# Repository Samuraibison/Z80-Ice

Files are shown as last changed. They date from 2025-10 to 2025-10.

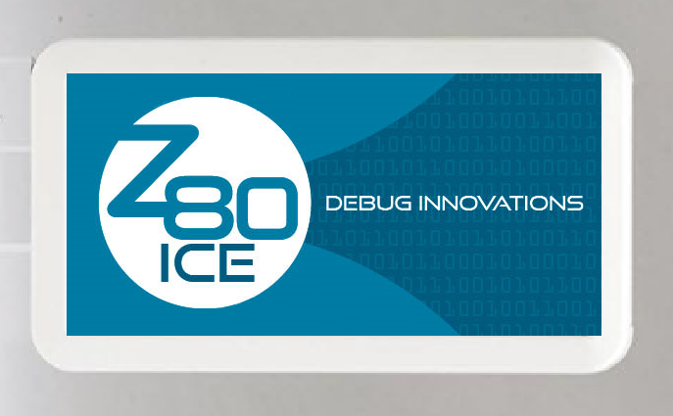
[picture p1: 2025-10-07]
Hardware/Box/Box_Label.png

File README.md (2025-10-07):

# Z80-Ice

**Work in Progress:** This project is still under development, and not all files are currently available.

## Foreword

All the source for this project was originally developed by **Dave Adshead**, under his company **Debug Innovations**. Unfortunately, Dave passed away in May 2025, so the resources here have been released for anybody interested in using it.

## About

The Z80 ICE is a project for a Z80 in-circuit emulator (ICE). The project aims to provide tools for debugging and developing Z80-based systems.

This repository contains:
- Firmware source code for the emulator.
- Hardware designs for the ICE.
- A basic desktop application for debugging.

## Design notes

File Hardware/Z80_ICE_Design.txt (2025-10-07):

ICE Options
===========

1. Design a Z80 in an FPGA
   Expensive, difficult to get right

2. Emulate a Z80 with a fast MCU
   May not be able to use the system clock
   Slow if all the pin timing is emulated

3. Control the clocks to the Z80
   No obvious way to set breakpoints
   No refresh when stopped
   Problems with interrupts, step over etc.
   Need target RAM to read/write registers etc.
   Need to mux the address bus between Z80 and PIC

4. Entirely soft solution using HALT for breakpoints
   User code can't use HALT
   Can't step through ROM code
   Need target RAM to read/write registers etc.
   Need to mux the address bus between Z80 and PIC

5. Our solution below...

See also http://www.primrosebank.net/computers/z80/z80_special_reset.htm
for short reset designed to be used with an ICE

Z80 ICE
=======

Z80 CPU (20MHz)
CPLD
64K x 8-bit breakpoint RAM
Control CPU (PIC) & debug interface

Debugger needs to be able to...

1. Reset CPU
2. Read/write system memory
3. Set/clear breakpoints
4. Set breakpoints
5. Read/write Z80 registers
6. Stop the CPU and read the PC

Breakpoint RAM bits
-------------------

0 : Code (execution) breakpoint
1 : Data read breakpoint
2 : Data write breakpoint
3 : Address is ROM / write protected (not implemented)

I/O read/write breakpoint??
Tracepoints?
Full trace?

The Z80 address bus is connected to the system and the
breakpoint RAM.  Z80 memory requests always read the
breakpoint RAM but the control lines nRD nWR etc. are gated
before they go to the system so that the requests can be
prevented from accessing system memory.  When running user
user code, all the control lines are active to the system.

The system provides the clock so it can't be stopped.

To stop the CPU, we could...

1. Stop the clock - that would stop refreshing DRAM or
2. Insert infinite wait states (addr wouldn't change).
   Would also stop DRAM refresh or
3. Execute NOPs (addr would go round 0-64K).  I suspect it
   would accept an interrupt, change addr, then continue
   executing NOPs and stay in interrupt state.
4. Execute a HALT - this would also jump on an interrupt.

These options all have problems so the scheme chosen is to
force 'Jump to self' instructions onto the data bus on every
instruction fetch.  This continues DRAM refresh and limits
the address change to 2 bytes.  This is called the idle state.

We gate INT and NMI when stopped to prevent the Z80 jumping
when we are pushing instructions on to the bus.

The Z80 reset goes through the PIC so we can reset the Z80
without resetting the system.

To limit the number of buffers/pins required, the address bus
is directly connected to the breakpoint RAM and system - the Z80
is the only output so the only way for the PIC to read/write
memory is to get the Z80 to do it via the CPLD.

The CPLD can force 1 or 2 byte instructions onto the data bus
in response to an instruction fetch and capture up to 2 bytes
of data written by the Z80.  At the end of every instruction,
the CPLD goes back to the idle state while the PIC loads the
CPLD registers with the next instruction.

We have to gate the control lines to the wider system so we
can read/write the breakpoint RAM without upsetting the system.
CPLD registers control whether the access goes to the breakpoint
RAM, the system memory or is captured by the CPLD registers.
A memory read puts data in the Z80 registers and the PIC can
then load an instruction to write the reg and capture the
data in the CPLD register.

When the Z80 stops, the registers are read in the following order:

1. The PC is read by executing a RST 0 instruction and capturing
   the stack writes.  The stopped PC is (return address - 1).
2. SP - the only way is to execute a LD (0),SP and capture the data.
3. AF, BC, DE, HL, IX, IY by PUSH instructions, capturing the data.
4. EX AF, AF' and EXX followed by PUSH AF, BC, DE, HL to get all
   the alternate registers then EXX back again.

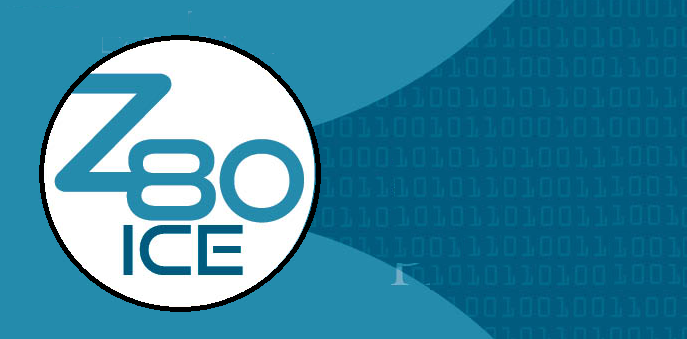
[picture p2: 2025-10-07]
Hardware/Box/Box2.png

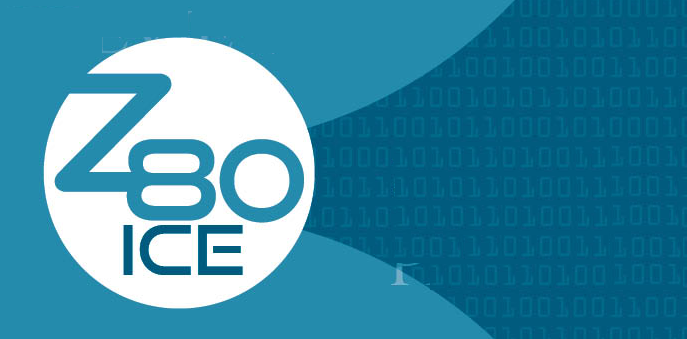
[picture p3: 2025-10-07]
Hardware/Box/Box1.png

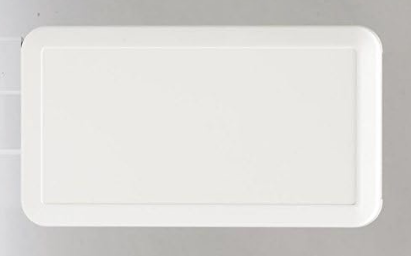
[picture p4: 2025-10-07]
Hardware/Box/Box.png

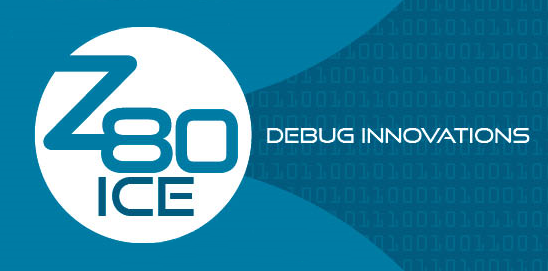
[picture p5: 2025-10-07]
Hardware/Box/Box3.png

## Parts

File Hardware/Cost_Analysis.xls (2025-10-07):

Production Cost Analysis
Item | Qty | Paid | Each
V1.2 PCBs from AllPCB | 10 | £700.94 | £70.09
Z80 CPUs | 50 | £550.50 | £11.01
Header PCBs | 50 | £157.62 | £3.15
IC pin conns | 50 | £38.76 | £0.78
SCSI conns | 10 | £77.00 | £7.70
SCSI cables | 7 | £72.52 | £10.36
SCSI cables | 3 | £24.27
Boxes | 10 | £360.00 | £36.00 |  | Est
TOTAL |  | £1981.61 | £139.09
Overheads
Label design |  | £125.76
Label printing | 100 | £39.18
TOTAL |  | £164.94
TOTAL SPEND |  | £2146.55
(excluding development)
Possible model prices
Z81 |  | £195 | $ 250 | €225
Z82 |  | £295 | $ 375 | €345
Z83 |  | £450 | $ 575 | €525
Screws?
Postage
Packing
PayPal fees?

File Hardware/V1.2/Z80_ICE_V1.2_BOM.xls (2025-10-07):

Z80 ICE V1.2 BOM, 11 July 2024
Designator | Part Type | Footprint | Qty | Part Number(s) | MOQ | Price (1 off) | Total per board | Comments
R1, R2 | 27R | 0805 | 2 | FN 244-7621 | 10 | 0.01 | 0.01
R3 | 47K | 0805 | 1 | FN 244-7664 | 10 | 0.01 | 0.01
R4-R35 | 47R | 0805 | 32 | FN 244-7666, RS 223-0253 | 10 | 0.01 | 0.24
R36, R37, R39 | 330R | 0805 | 3 | FN 244-7638, RS 223-0354 | 10 | 0.01 | 0.02
R38 | 1K0 1% | 0805 | 1 | FN 244-7587, RS 223-0427 | 10 | 0.01 | 0.01
R40-R44 | 10K | 0805 | 5 | FN 244-7553, RS 223-0562 | 10 | 0.01 | 0.03
R45 | 2K0 1% | 0805 | 1 | FN 244-7622, RS 901-3686 | 10 | 0.01 | 0.01
RP1 | 100K | SIL-9 | 1 | MS 652-4609X-1LF-100K |  | 0.16 | 0.16
 |  |  |  |  |  | RESISTORS | 0.49
C1 | 10nF | 0805 | 1 | FN 940-6352 | 10 | 0.07 | 0.07
C2, C3 | 47pF | 0805 | 2 | FN 136-2560 | 10 | 0.03 | 0.06
C4 | 4.7uF | 0805 | 1 | FN 175-9427 | 5 | 0.14 | 0.14
C5 | 10uF | 0805 | 1 | FN 301-3456 | 5 | 0.04 | 0.04
C6-C21 | 100nF | 0805 | 16 | FN 940-6409, RS 220-7966, RS 464-6688P | 10 | 0.05 | 0.88
 |  |  |  |  |  | CAPACITORS | 1.19
D1-D3 | Green | 1206 | 3 | FN 855-4595, RS 486-0531 | 5 | 0.45 | 1.34
D4 | BAT54A | SOT-23 | 1 | FN 267-7689, FN 267-5345 | 5 | 0.09 | 0.09
 |  |  |  |  |  | DIODES | 1.43
U1 | Z80 CPU | DIP-40 | 1 | MS 692-Z84C0020PEG (20MHz) |  | 14.49 | 14.49
U2 | FT230XS | SSOP-16 | 1 | FN 208-1321, RS 757-0010 |  | 2.11 | 2.11
U3 | PIC18F27Q43 | SOIC-28 | 1 | DK 150-PIC18F27Q43-I/SO-ND |  | 1.87 | 1.87
U4 | IDT71024 | SOJ-32/400 | 1 | FN 338-1437, FN 211-5419 |  | 3.48 | 3.48
U5 | XC9572XL | QFP-44 | 1 | FN 361-7886, FN 283-1287, MS 217-XC9572XL-10VQ44C |  | 7.59 | 7.59
U6 | MCP1700-3.3V | SOT-23 | 1 | FN 129-6592, RS 698-9044, DK MCP1700T3302ETTCT-ND, FUT MCP1700T-3302E/TT |  | 0.41 | 0.41
U7-U9 | 74AC244 | SOIC-20 | 3 | FN 101-4154 |  | 0.55 | 1.64
U10, U11 | 74ACT32 | SOIC-14 | 2 | FN 272-4117 |  | 0.51 | 1.01
U12 | 74ACT00 | SOIC-14 | 1 | FN 284-5050 |  | 0.56 | 0.56
 |  |  |  |  |  | INTEG CIRCUITS | 33.16
J1 | USB | CONN_USB_B | 1 | FN 146-3095, FN 107-6665, RS 515-1967, RS 529-8218 |  | 1.14 | 1.14
J2 | Header | CONN_SCSI68 | 1 | FN 237-3611 |  | 9.95 | 9.95
J3 | PIC | CONN_SIP5 | 1 | DK S1211EC-05-ND |  | 0.15 | 0.15
 |  |  |  |  |  | CONNECTORS | 11.24
L1 | BEAD | 0805 | 1 | RS 724-1542, FN 305-6521, DK 490-1053-1-ND |  |  | 0.00
Box | Plastic | 135x76x35mm | 1 | FN 339-0120, CPC EN83790, real Takachi part no. is LC135H-N-W |  | 8.45 | 8.45
PCB Screws |  |  | 6 | MS 538-73726-0015 |  | 0.58 | 3.48
 |  |  |  |  |  | OTHER | 11.93
 |  | TOTAL NUMBER OF COMPONENTS | 94 |  |  | TOTAL COST OF COMPONENTS | 59.45

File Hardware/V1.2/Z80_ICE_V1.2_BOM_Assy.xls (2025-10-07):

Z80 ICE V1.2 BOM, 20 May 2024
 |  |  |  | Joints
Designator | Part Type | Footprint | Qty | SMD | TH | Part Number(s) | Comments
R1, R2 | 27R | 0805 | 2 | 4 |  | FN 244-7621
R3 | 47K | 0805 | 1 | 2 |  | FN 244-7664
R4-R35 | 47R | 0805 | 32 | 64 |  | FN 244-7666, RS 223-0253
R36, R37, R39 | 330R | 0805 | 3 | 6 |  | FN 244-7638, RS 223-0354
R38 | 1K0 1% | 0805 | 1 | 2 |  | FN 244-7587, RS 223-0427
R40-R44 | 10K | 0805 | 5 | 10 |  | FN 244-7553, RS 223-0562
R45 | 2K0 1% | 0805 | 1 | 2 |  | FN 244-7622, RS 901-3686
RP1 | 100K | SIL-9 | 1 |  | 9 | MS 652-4609X-1LF-100K
C1 | 10nF | 0805 | 1 | 2 |  | FN 940-6352
C2, C3 | 47pF | 0805 | 2 | 4 |  | FN 136-2560
C4 | 4.7uF | 0805 | 1 | 2 |  | FN 175-9427
C5 | 10uF | 0805 | 1 | 2 |  | FN 301-3456
C6-C21 | 100nF | 0805 | 16 | 32 |  | FN 940-6409, RS 220-7966, RS 464-6688P
D1-D3 | Green | 1206 | 3 | 6 |  | FN 855-4595, RS 486-0531
D4 | BAT54A | SOT-23 | 1 | 3 |  | FN 267-7689, FN 267-5345
U1 | Socket | DIP-40 | 1 |  | 40 | 40w turned pin IC socket
U2 | FT230XS | SSOP-16 | 1 | 16 |  | FN 208-1321, RS 757-0010
U3 | PIC18F27Q43 | SOIC-28 | 1 | 28 |  | DK 150-PIC18F27Q43-I/SO-ND
U4 | IDT71024 | SOJ-32/400 | 1 | 32 |  | FN 338-1437, FN 211-5419
U5 | XC9572XL | QFP-44 | 1 | 44 |  | FN 361-7886, FN 283-1287, MS 217-XC9572XL-10VQ44C
U6 | MCP1700-3.3V | SOT-23 | 1 | 3 |  | FN 129-6592, RS 698-9044, DK MCP1700T3302ETTCT-ND, FUT MCP1700T-3302E/TT
U7-U9 | 74AC244 | SOIC-20 | 3 | 60 |  | FN 101-4154
U10, U11 | 74ACT32 | SOIC-14 | 2 | 28 |  | FN 272-4117
U12 | 74ACT00 | SOIC-14 | 1 | 14 |  | FN 284-5050
J1 | USB | CONN_USB_B | 1 |  | 6 | FN 146-3095, FN 107-6665, RS 515-1967, RS 529-8218
J2 | Header | CONN_SCSI68 | 1 |  | 68 | FN 237-3611
J3 | PIC | CONN_SIP5 | 1 |  | 5 | DK S1211EC-05-ND
L1 | BEAD | 0805 | 1 | 2 |  | RS 724-1542, FN 305-6521, DK 490-1053-1-ND
 |  | TOTAL NUMBER OF COMPONENTS | 87
 |  | TOTAL SMD JOINTS |  | 368
 |  | TOTAL TH JOINTS |  |  | 128
 |  | TOTAL SOLDER JOINTS |  |  | 496

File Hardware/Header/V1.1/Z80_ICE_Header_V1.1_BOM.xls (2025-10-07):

Z80 ICE Header V1.1 BOM, 19 June 2024
Designator | Part Type | Footprint | Qty | Part Number(s) | MOQ | Price (1 off) | Total per board | Comments
R1 | 47R | 0402 | 1 |  | 10 | 0.01 | 0.01
R2-R6 | 100R | 0402 | 5 |  | 10 | 0.01 | 0.03
 |  |  |  |  |  | RESISTORS | 0.04
J1, J2 | IC Pins | CONN_SIP20 | 2 | RS 674-2309, MS 437-8001002010001101, DK ED7264-20-ND | 5 | 2.20 | 4.40 | Solder the long thick pins. The short thin pins plug into IC socket.
J3 | ICE | CONN_SCSI68 | 1 | FN 237-3611 |  | 9.85 | 9.85
 |  |  |  |  |  | CONNECTORS | 14.25
 |  | TOTAL NUMBER OF COMPONENTS | 9 |  |  | TOTAL COST OF COMPONENTS | 14.29
Alternative connectors:
https://www.switchelectronics.co.uk/20-way-2-54mm-turned-pin-single-in-line-sil-header |  |  |  |  |  |  |  | 55p each, 20 way
https://www.amazon.co.uk/2-54MM-40WAY-TURNED-HEADERS-PACK/dp/B01HZU84Z0
Cheaper 40 way breakable strips, not guaranteed to come complete, < £1 per strip (50p for 20 way)

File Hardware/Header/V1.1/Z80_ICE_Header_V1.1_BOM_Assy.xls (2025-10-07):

Z80 ICE Header V1.1 BOM, 19 June 2024
 |  |  |  | Joints
Designator | Part Type | Footprint | Qty | SMD | TH | Part Number(s) | Comments
R1 | 47R | 0402 | 1 | 2
R2-R6 | 100R | 0402 | 5 | 10
J1, J2 | IC Pins | CONN_SIP20 | 2 |  | 40 | RS 674-2309, MS 437-8001002010001101, DK ED7264-20-ND | Solder the thick pins
J3 | ICE | CONN_SCSI68 | 1 |  | 68 | FN 237-3611
 |  | TOTAL NUMBER OF COMPONENTS | 9
 |  | TOTAL SMD JOINTS |  | 12
 |  | TOTAL TH JOINTS |  |  | 108
 |  | TOTAL SOLDER JOINTS |  |  | 120

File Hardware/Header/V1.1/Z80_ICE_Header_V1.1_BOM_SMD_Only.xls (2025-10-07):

Z80 ICE Header V1.1 BOM, 19 June 2024
 |  |  |  | Joints
Designator | Part Type | Footprint | Qty | SMD | TH | Part Number(s) | Comments
R1 | 47R | 0402 | 1 | 2 |  | Any
R2-R6 | 100R | 0402 | 5 | 10 |  | Any
J1, J2 | IC Pins | CONN_SIP20 | 2 |  | 40 |  | DO NOT FIT, leave holes free of solder
J3 | ICE | CONN_SCSI68 | 1 |  | 68 |  | DO NOT FIT, leave holes free of solder
 |  | TOTAL NUMBER OF COMPONENTS | 9
 |  | TOTAL SMD JOINTS |  | 12
 |  | TOTAL TH JOINTS |  |  | 108
 |  | TOTAL SOLDER JOINTS |  |  | 120

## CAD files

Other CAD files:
Hardware/Box/Manufacturer_Data/LC135H-N-W.dxf
Hardware/Box/Manufacturer_Data/LC135H-N-W.dwg

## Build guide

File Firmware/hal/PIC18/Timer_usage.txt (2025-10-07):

Timer usage in PIC18 HAL
========================

Timer 0   : hal_time.c    Main 1ms timer tick and timer_delay_us()
Timer 3/5 : hal_time.c    Microsecond timer for timer_set_timeout()
Timer 6   : i2c_master.c  I2C clock divider

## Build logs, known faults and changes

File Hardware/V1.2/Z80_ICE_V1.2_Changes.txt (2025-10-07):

Z80 ICE Changes V1.1->V1.2
==========================

Electrical
----------

 1. ZVCC can be higher than VCC (from USB) so the PIC ZVCC pin has been potted down

 2. The PIC GND pins are not connected together directly - extra vias added

 3. USB trace routing improved (tracks ran together for a short distance - differential impedance)

 4. Target Vcc is quite noisy - added a cap at the connector

 5. BUSY LED (D3) turned round so it is the same way round as the other LEDs

 6. C14 moved further away from U4

 7. Legend placement improved, no legends are under parts anymore

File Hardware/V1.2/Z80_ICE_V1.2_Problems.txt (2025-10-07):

Z80 ICE V1.2 Problems
=====================

Electrical
----------

 1. Target power supplies phantom power to ICE when ICE USB is not plugged in.

 2. Do we need to power the output buffers from ZVCC so they don't output a higher voltage than
    the target system ?

 3. It doesn't work at 20MHz (only 18MHz with a short cable).  Observing signals on the
    system Z80 socket, when running at 16MHz, the clock arrives at the ICE Z80 clock pin
    with very little delay although the edges are quite slow.  Then the control signals
    such as nM1, nMREQ, nRD etc. arrive at the system socket with about half a clock cycle
    delay (31ns).  Some of the delay is in the Z80, almost none in the gates, about 12ns in
    the HC244 buffer and none in the 47R resistor.  We can improve the timing by about 6ns
    by switching to AC244 buffers and square up the clock by reducing the 47R on the adaptor
    board to 22R?  The reality is that the Z80 signals come out too late to allow it to work
    at 20MHz so we need a new CPLD design - not sure how it might be fixed??  Re-evaluate
    on V1.1 PCBs.

Mechanical
----------

 1. 

Improvements for next board
---------------------------

 1. 

Manufacturing problems
----------------------

 1. 

Future ideas
------------

 1. Use an ARM for improved performance and added pins.  Will support DFU.  5V pins??
    Need to connect HALT and NMI lines to CPU (see 2 below).

 2. Connect more SRAM data pins to the CPLD for other breakpoint reasons we may implement.
    For example a breakpoint on 0x66 gated with a CPU signal so we can set it when the Z80
    is running and break out of a HALT state by generating an NMI.

 3. Have an external breakpoint input so an event can stop the code.

 4. Power & busy LEDs on outside of box?

 5. Faster Z80, Z180, eZ80 etc?

PCB Modifications
-----------------

 1. 

Interrupt problem
-----------------

If an interrupt is recognised during the instruction before a breakpoint, the Z80 starts an interrupt
acknowledge cycle which consists of nM1 and nIORQ going low.  Unfortunately we have to recognise the
breakpoint on the nM1 half a cycle before nMREQ so we can gate off nRD to the system in time to stop
a valid memory cycle for the system.  This means that the breakpoint is recognised due to nM1 going
low on an interrupt acknowledge cycle and the PC ends up on the interrupt vector.

This is guaranteed to happen whenever the interrupts are enabled by an EI RET sequence if there is a
breakpoint on the return address.  That's why the Z80 version of chip_enable_interrupts() has a NOP.

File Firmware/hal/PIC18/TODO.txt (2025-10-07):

PIC HAL Problems
================

Sleep mode on PIC18F and probably PIC16F18857 - current consumption barely changes
Looks to be something to do with the USB converter cable.  Connecting TXD pushes the current
up by ~20mA when PIC is running from 5V.  Need to re-test with 3.3V and understand mechanism.
Also, re-connecting TXD seems to fix it !

XC8 V2.2 on PIC18F, -O2 doesn't work (GPIOs won't toggle in a simple loop).  -O0 and -O1 are fine.

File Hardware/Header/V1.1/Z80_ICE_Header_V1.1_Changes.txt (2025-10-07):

Header Changes V1.0->V1.1
=========================

 1. Moved the resistors to the top side so they aren't damaged by levering it out of the socket
    with a screwdriver

 2. Moved some of the legends and put a square around pin 1

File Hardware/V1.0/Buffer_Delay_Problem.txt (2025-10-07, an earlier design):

File Buffer_Delay_HC.png
------------------------

CPU clock is 16MHz in the picture

Yellow: Clock on Elektor board (source of Z80 clock)
Blue:   Z80 clock on ICE (about 4ns delayed from yellow trace)
Pink:   nMREQ output of Z80 on ICE
Green:  nMREQ on Elektor board (16ns delayed)

All the control signals go through 74HC244 buffers and some gates.
The gates don't delay the signals much so the HC244's are responsible
for the majority of the 16ns delay.

ICE and debugger seem to stop working above ~18.3MHz (won't step properly)

File Buffer_Delay_AC.png
------------------------

Same probes as above.

U9 (74HC244 buffer) changed for a 74AC244.
nMREQ delay is now 10ns, an improvement of 6ns.
Edges are faster and overshoot at the Elektor board.

Still works at 18MHz but no higher.

Update: Runs at 20MHz, steps most instructions but ADD A,B doesn't step
(it appears to see the breakpoint on the ADD and fail to start).

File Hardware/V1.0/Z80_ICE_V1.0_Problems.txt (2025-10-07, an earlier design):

Z80 ICE V1.0 Problems
=====================

Electrical
----------

 1. nMREQ shouldn't be gated with nSYSSIG in U10B because nMREQ needs to remain active with
    nRFSH to refresh DRAMs in the idle state when nSYSSIG is high, see mod 1.

 2. Interrupt enable signal needs to be generated by the CPLD because of a timing hazard
    (see TODO in cpld.c).  See mod 2.

 3. The BUSY LED connected to PGD stops the PIC debugger working.  Could connect the LED to
    GND instead so it becomes a pull-down.

 4. Signals from the ICE supply parasitic power to the target.  U7-U9 outputs need to be
    tri-stated if there is no target power.  Also change RP1 to 100K, see mod 3.

 5. SD0-SD2 need 4k7 pull-downs or the signal stays high when the SRAM stops driving the bus.
    Check why that is a problem (it was needed on the breadboard build).  Done a software
    workaround which seems to work.  I now think this is a red herring - the prototype would
    work without the pull down if we used the latest CPLD design.

 6. It doesn't work at 20MHz (only 18MHz with a short cable).  Observing signals on the
    system Z80 socket, when running at 16MHz, the clock arrives at the ICE Z80 clock pin
    with very little delay although the edges are quite slow.  Then the control signals
    such as nM1, nMREQ, nRD etc. arrive at the system socket with about half a clock cycle
    delay (31ns).  Some of the delay is in the Z80, almost none in the gates, about 12ns in
    the HC244 buffer and none in the 47R resistor.  We can improve the timing by about 6ns
    by switching to AC244 buffers and square up the clock by reducing the 47R on the adaptor
    board to 22R?  See mod 4.

Mechanical
----------

 1. USB conn should be 0.6mm farther to the right to be flush with case external face.

 2. J2 is designed to go on the edge of the PCB and it has a ridge which extends beyond the
    PCB edge.  As a result it doesn't fit flush to the PCB and has to be fitted at an angle
    or raised manually to solder it flat (but raised).  Maybe cut the end off the PCB so it
    fits on the end and get rid of 2 mounting holes or use the same connector as the Z80
    socket adaptor.

Improvements for next board
---------------------------

 1. Use U10B to replace U12A/B.  U12 is no longer required after parasitic power fix
    below but 2 NANDs and an inverter are added.

 2. To fix electrical problem 4 (parasitic power)...
      a) In software, if ZVCC is too low or there is no clock coming from the system,
         hold the Z80 and CPLD in reset to stop parasitic power from the data bus.
      b) Replace U12C with a NAND gate with nBACK and nZ80RST as inputs.  Connect the
         output to U7 & U8 (U9A pin 1 no longer driven from this gate).
      c) Use another NAND gate to drive U9A pin 1 with inputs connected to nBACK and
         nRSTOUT from the PIC.
      d) Invert nRSTOUT from the PIC and connect it to U9B pin 19.
      e) Swap RP1 for a 100K version.

 3. Decoupling cap grounds could be shorter/better e.g. the SRAM

Manufacturing problems
----------------------

 1. 

Future ideas
------------

 1. Possibly drive nCTS on the FTDI chip to force it to send the buffered data to the PC.
    We'd need to find a PIC pin/signal we can re-use.

 2. Power & busy LEDs on outside of box?

PCB Modifications
-----------------

 1. Lift U10 pin 5 and connect pin 5 to pin 4.

 2. Cut track on solder side (blue) from U1 pin 20 to U5 pin 5 (nIORQ).
    Cut track on component side (red) from U3 pin 9 to U11 before it gets to the via under U1 (nINTEN).
    On the solder side (blue), connect the nINTEN via near U1 pins 15 & 16 to the U5 pin 5 via (nIORQ) with a wire.
    On the component side (red), connect U5 pin 38 to U3 pin 9 with a wire - now called INTBLK.

 3. Replaced RP1 with 100K version.

 4. Replaced U7-U9 with 74AC244.

Mod 2 corner case
-----------------

If an interrupt is recognised during the instruction before a breakpoint, the Z80 starts an interrupt
acknowledge cycle which consists of nM1 and nIORQ going low.  Unfortunately we have to recognise the
breakpoint on the nM1 half a cycle before nMREQ so we can gate off nRD to the system in time to stop
a valid memory cycle for the system.  This means that the breakpoint is recognised due to nM1 going
low on an interrupt acknowledge cycle and the PC ends up on the interrupt vector.

This is guaranteed to happen whenever the interrupts are enabled by an EI RET sequence if there is a
breakpoint on the return address.  That's why the Z80 version of chip_enable_interrupts() has a NOP.

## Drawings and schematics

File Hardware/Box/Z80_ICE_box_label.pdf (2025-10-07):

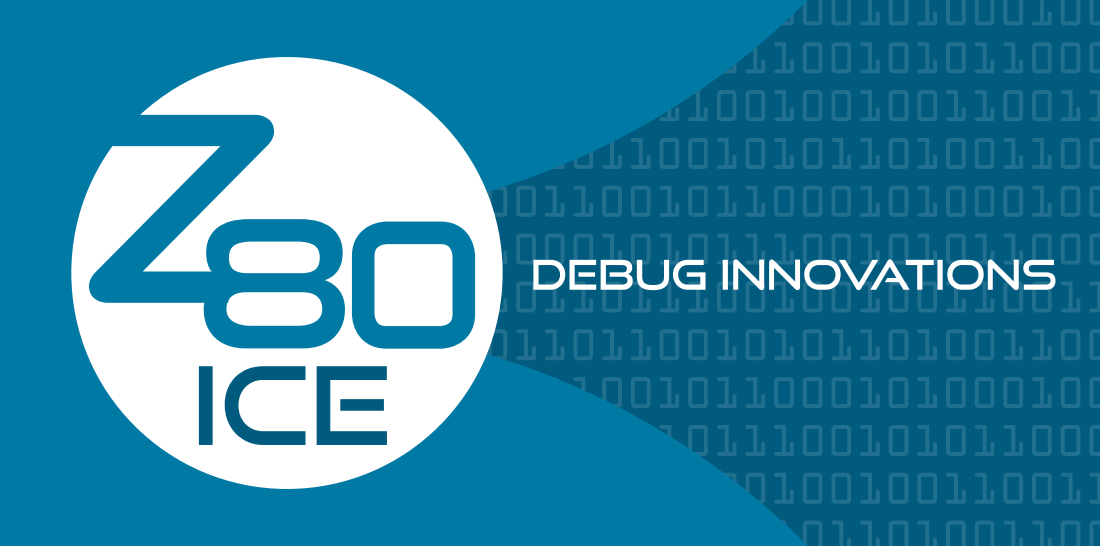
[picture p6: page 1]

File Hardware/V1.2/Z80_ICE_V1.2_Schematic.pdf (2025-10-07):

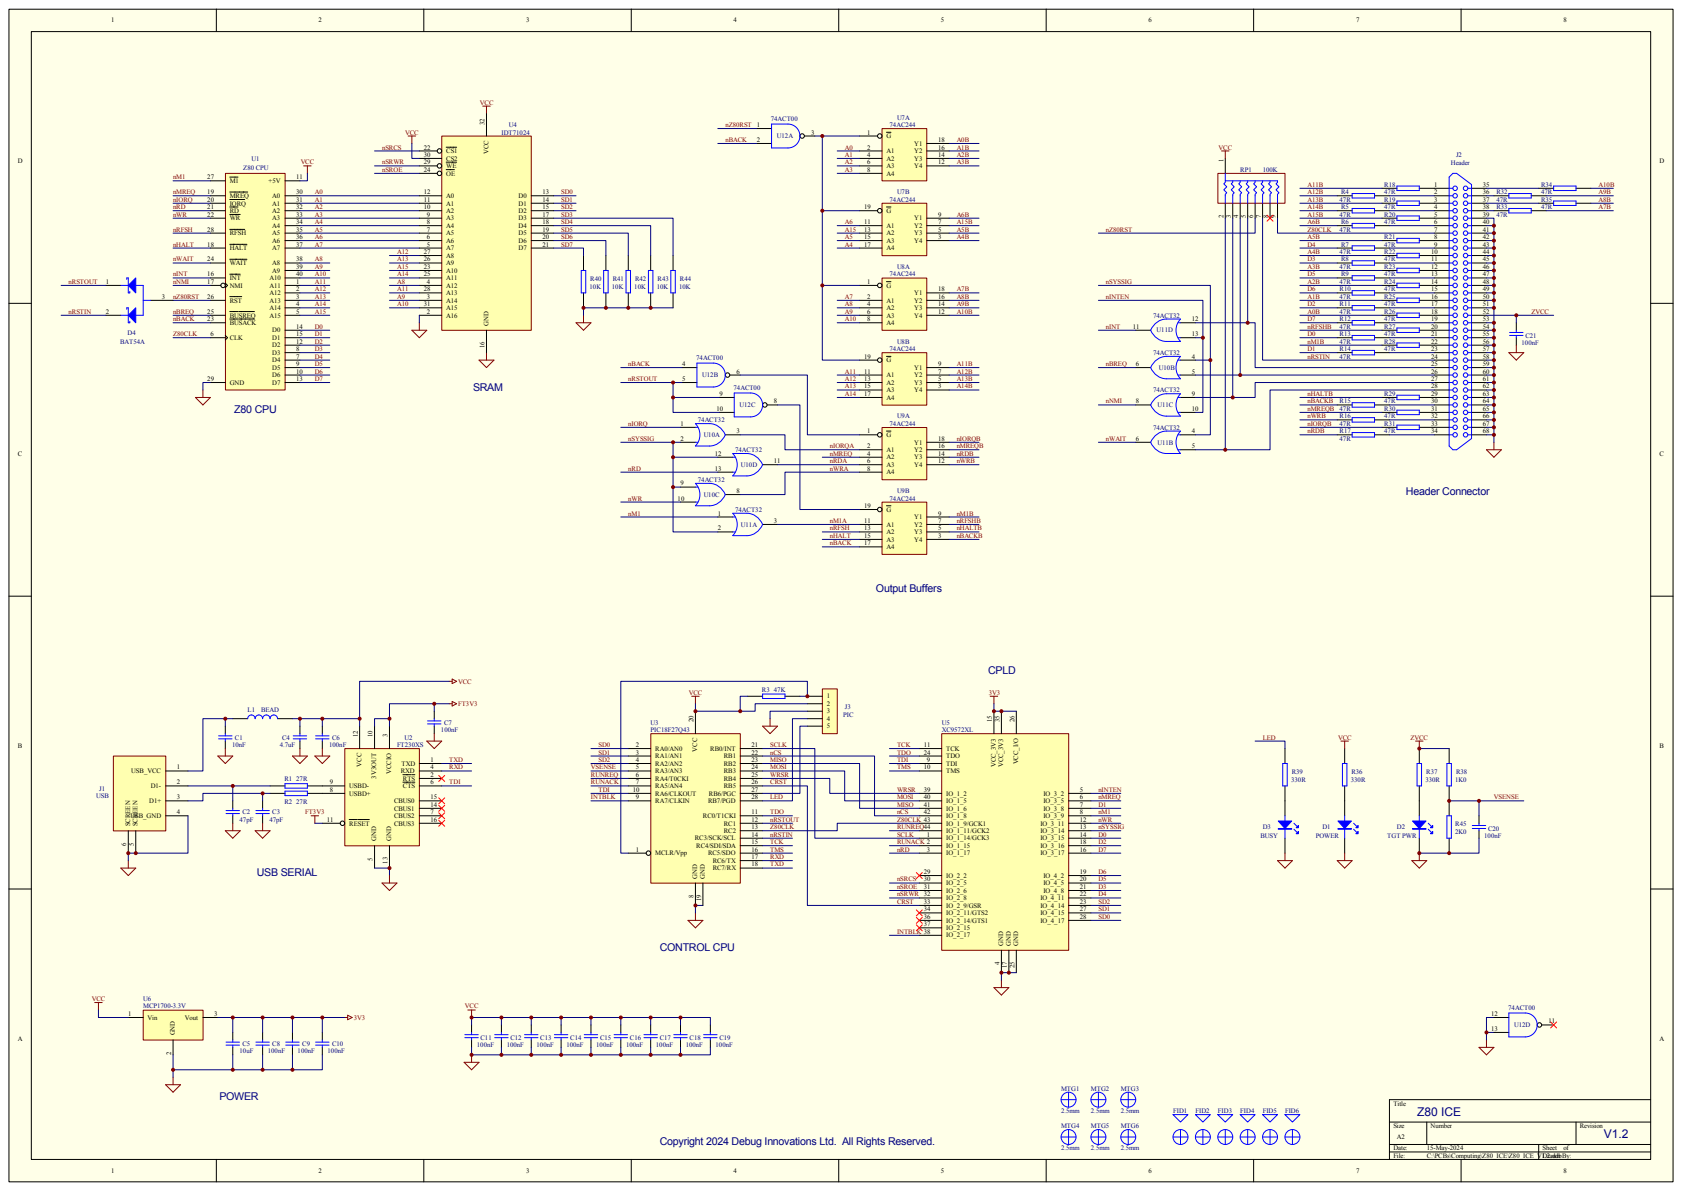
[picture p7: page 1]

V1.2 Copyright 2024 Debug Innovations Ltd. All Rights Reserved.

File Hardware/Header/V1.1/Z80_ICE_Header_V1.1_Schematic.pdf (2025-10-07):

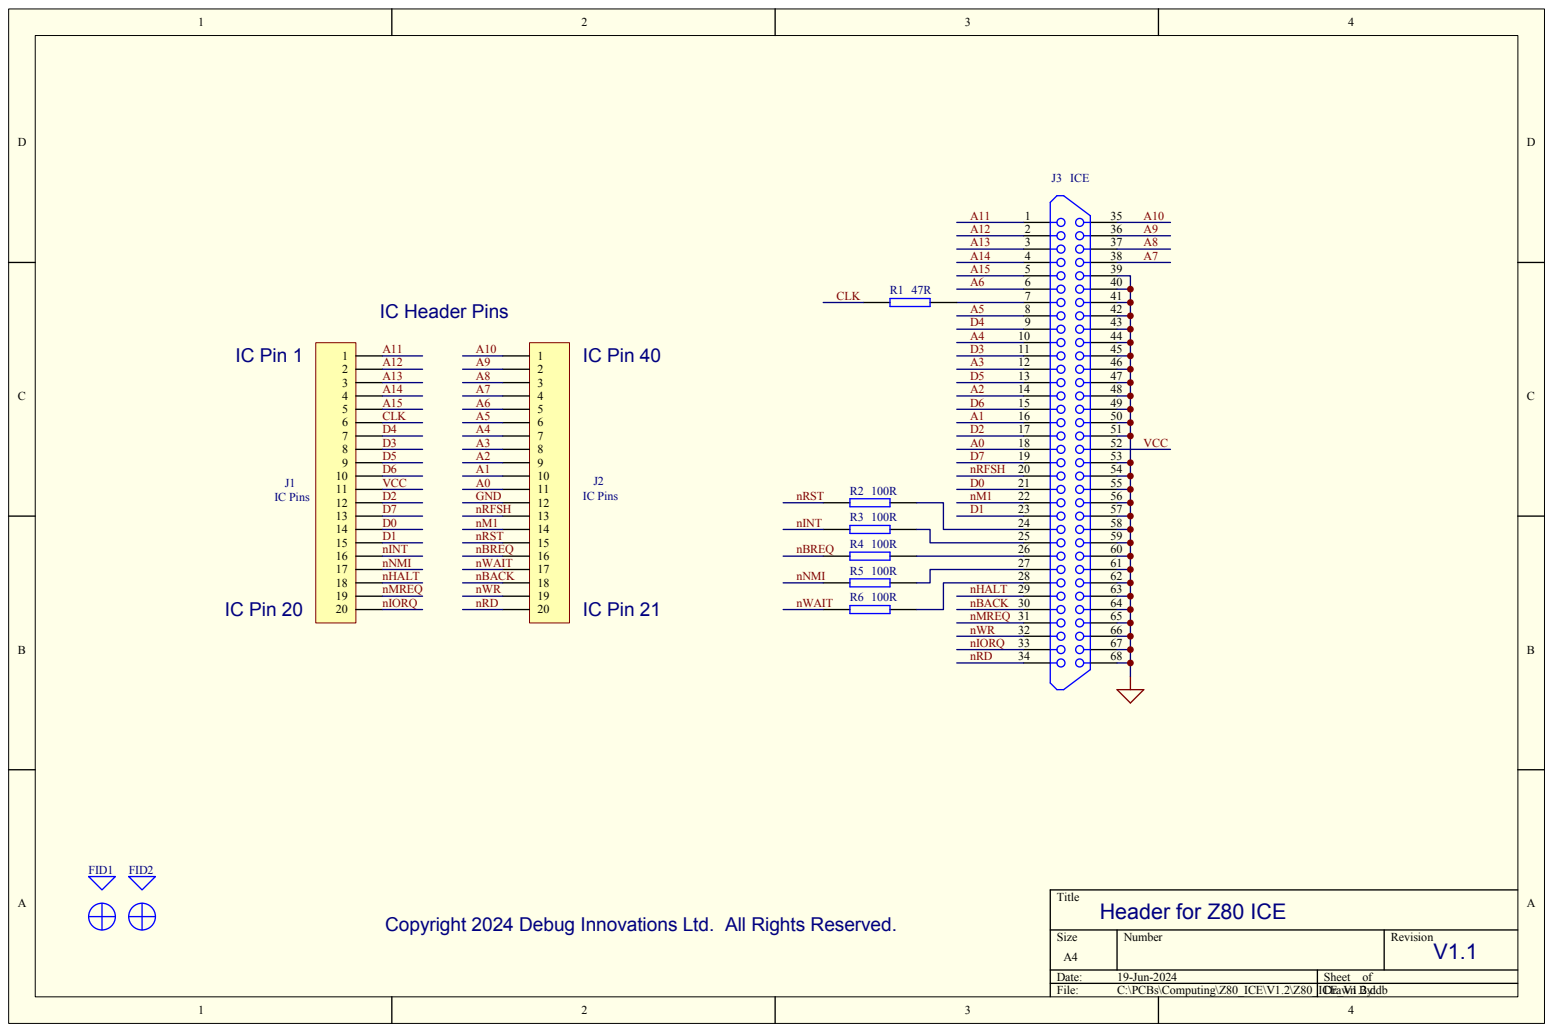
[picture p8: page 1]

Copyright 2024 Debug Innovations Ltd. All Rights Reserved.

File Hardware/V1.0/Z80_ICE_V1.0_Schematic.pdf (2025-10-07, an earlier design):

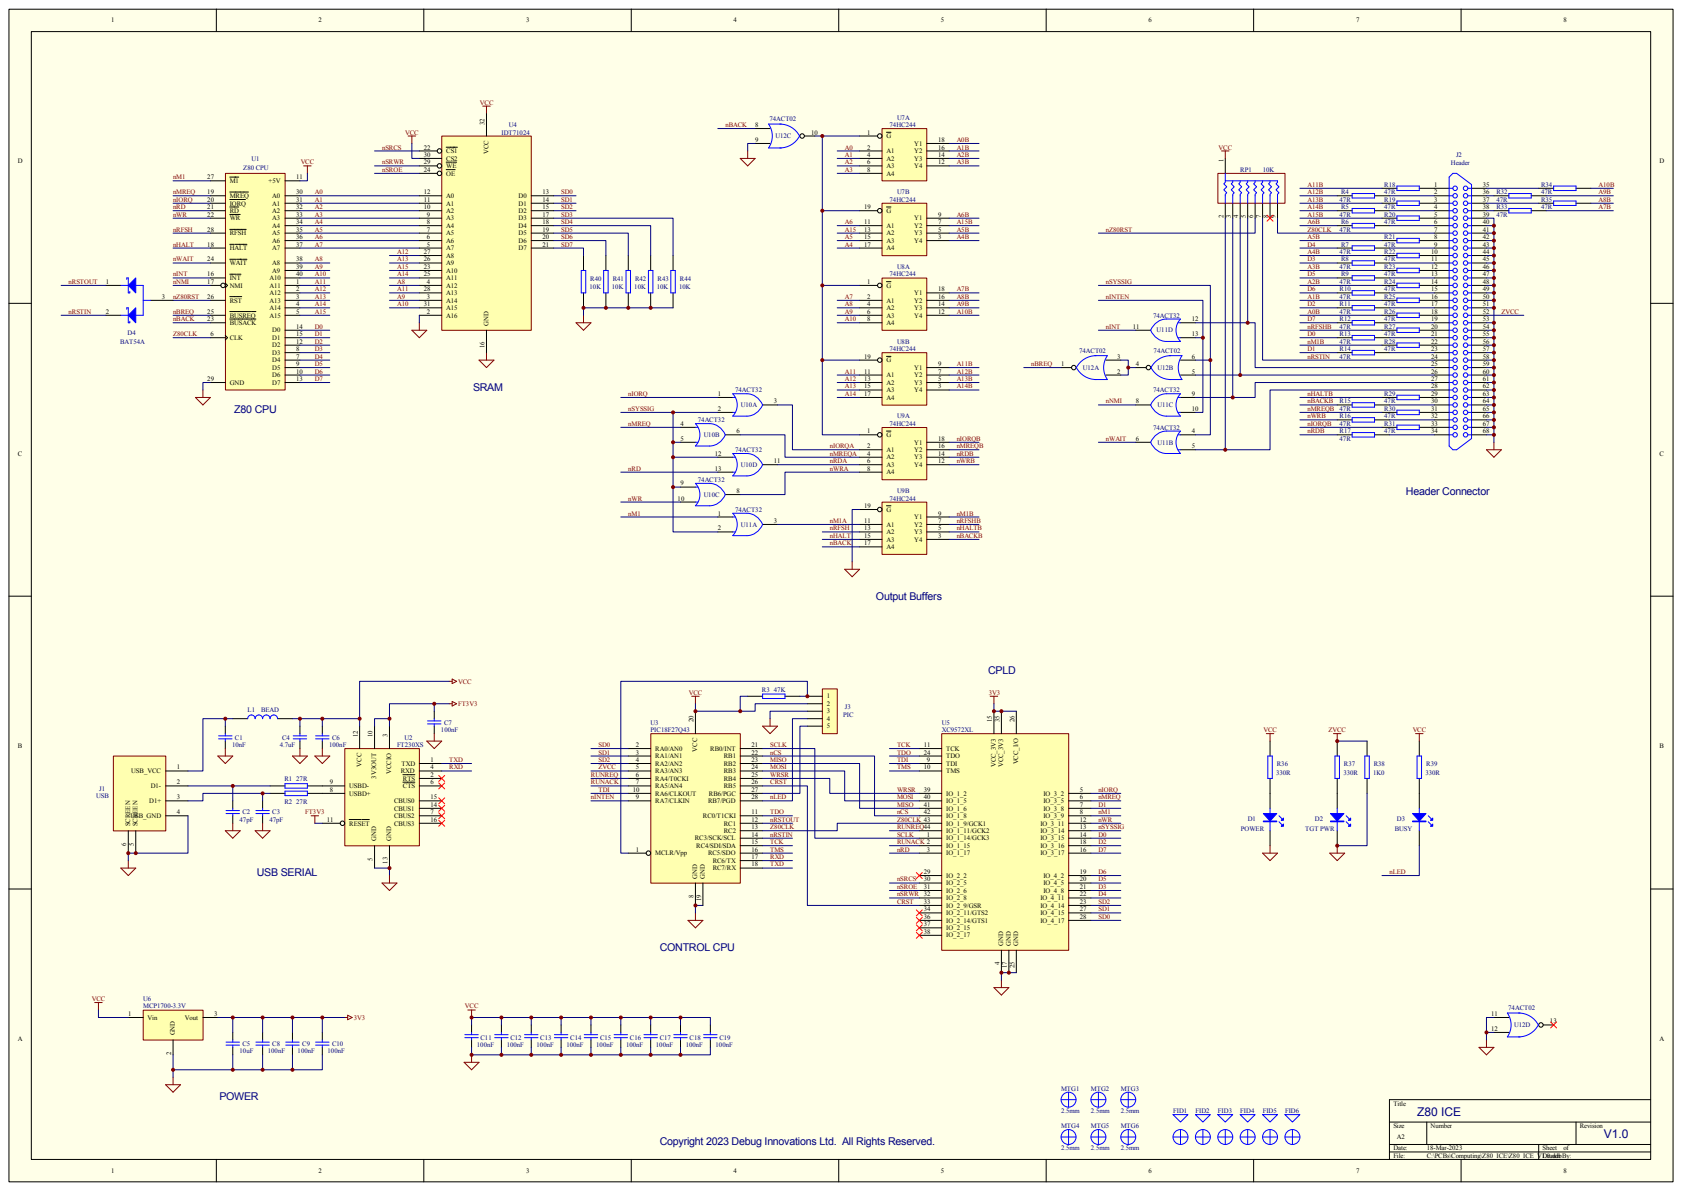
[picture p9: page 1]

V1.0 Copyright 2023 Debug Innovations Ltd. All Rights Reserved.

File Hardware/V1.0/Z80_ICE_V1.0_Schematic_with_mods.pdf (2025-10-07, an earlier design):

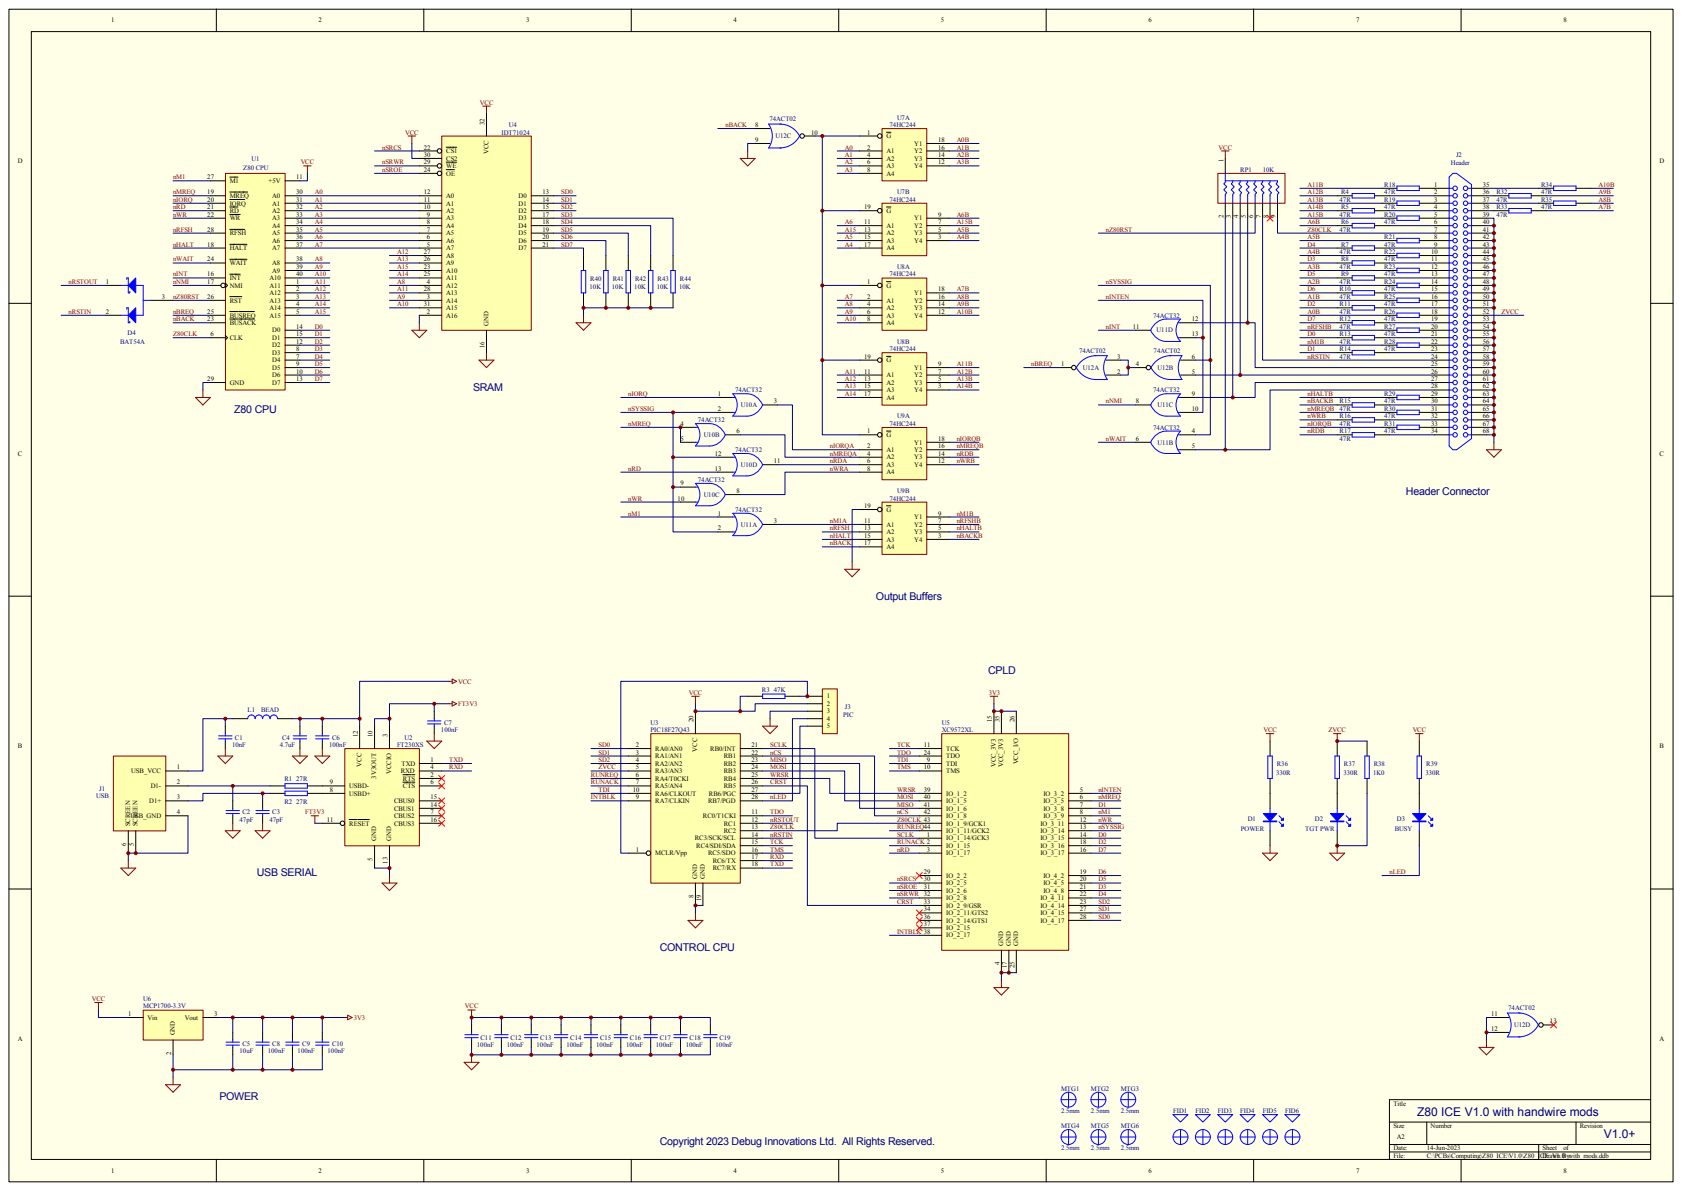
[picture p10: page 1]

Title
Z80 ICE V1.0 with handwire mods

V1.0+ Copyright 2023 Debug Innovations Ltd. All Rights Reserved.

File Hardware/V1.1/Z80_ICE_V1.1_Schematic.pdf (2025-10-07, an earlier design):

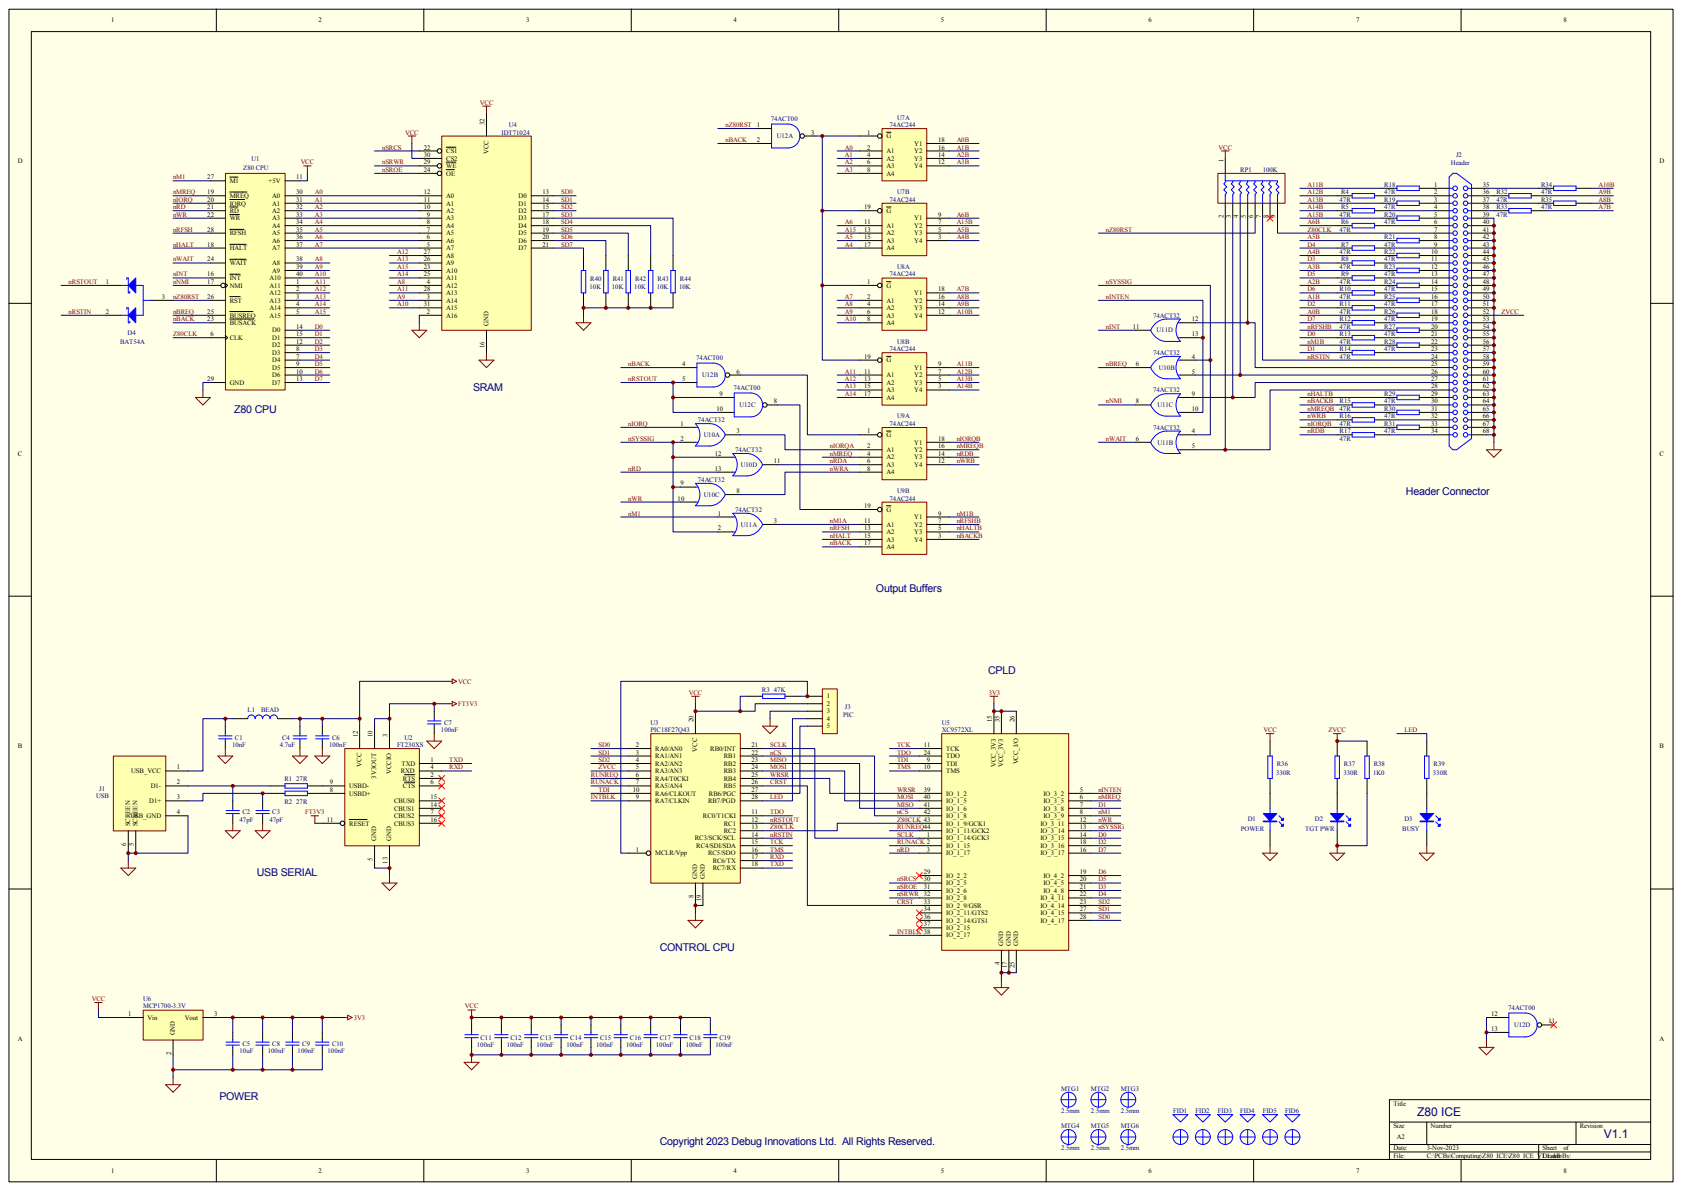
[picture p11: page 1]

V1.1 Copyright 2023 Debug Innovations Ltd. All Rights Reserved.

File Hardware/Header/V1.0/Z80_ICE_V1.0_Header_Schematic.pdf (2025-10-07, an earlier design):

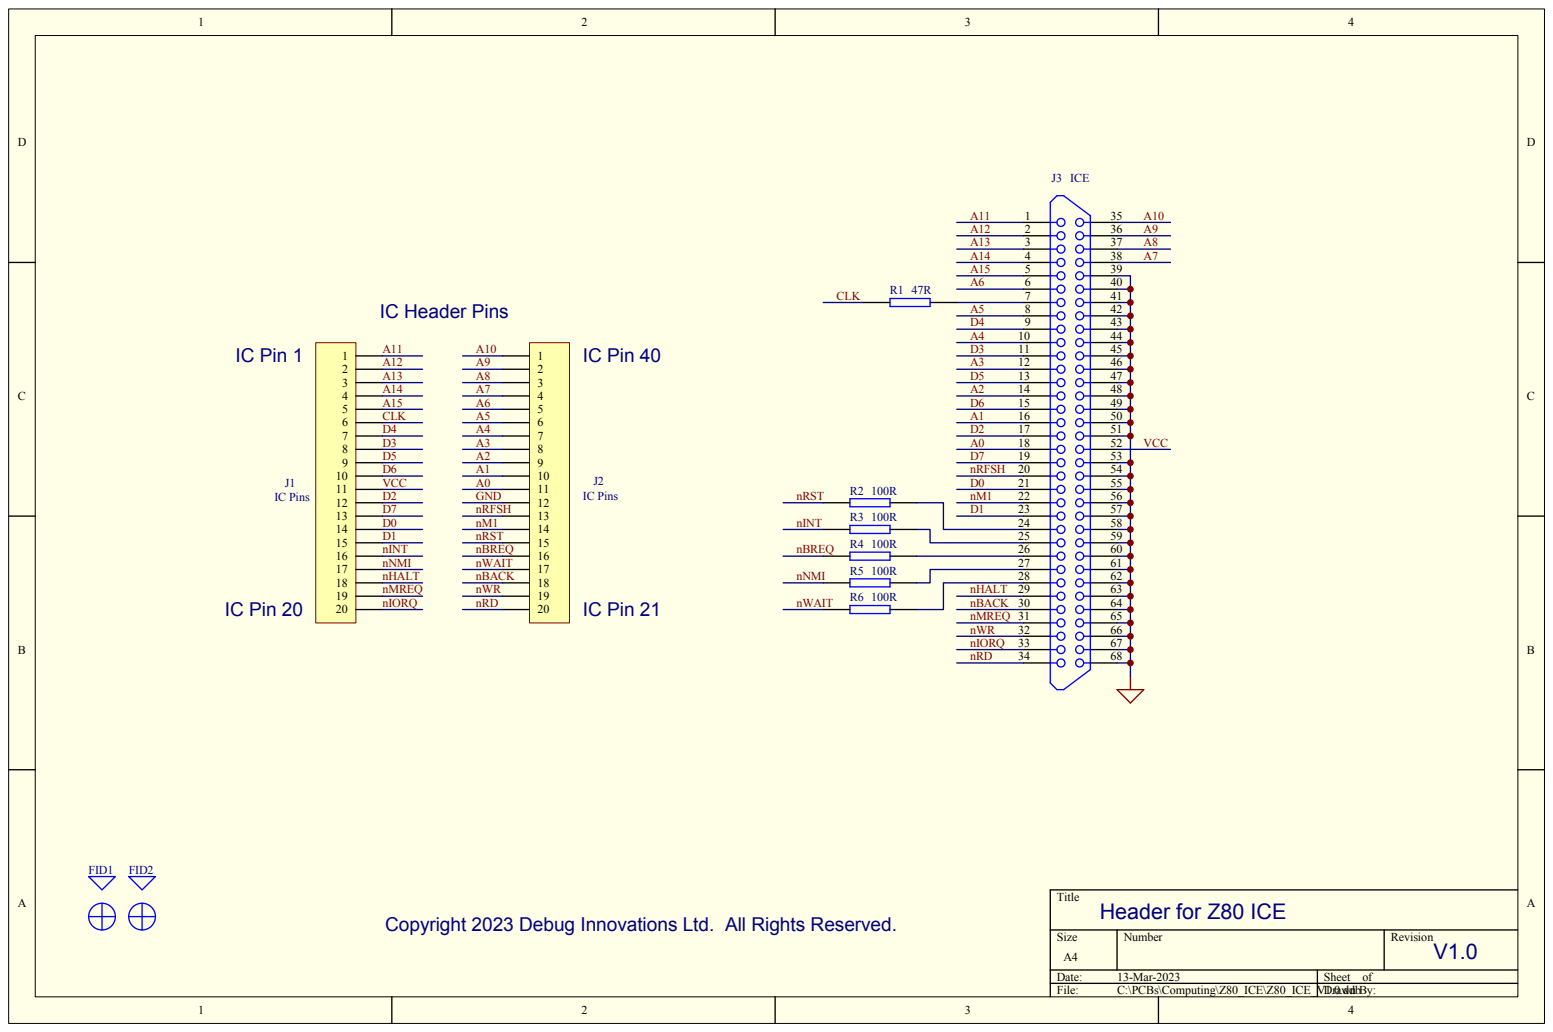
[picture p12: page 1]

Copyright 2023 Debug Innovations Ltd. All Rights Reserved.

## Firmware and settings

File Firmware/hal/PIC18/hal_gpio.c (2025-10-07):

/**
 * @brief PIC18 HAL GPIO and ADC driver
 *        Note: Interrupts rely on GIE being set
 *
 * The following devices plus their LF equivalents are supported:
 *   PIC18F 25K83
 *          26K83
 *          26Q10
 *          26Q43
 *          27Q43
 *
 * Copyright Debug Innovations Ltd. 2018-2024
 */

// Suppress some annoying XC8 compiler warnings, mostly because
// different bits of code are used with different PICs
#pragma warning disable 373   // Signed to unsigned conversions
#pragma warning disable 520   // Uncalled functions
#pragma warning disable 1090  // Unused variables
#pragma warning disable 759   // Expression generates no code
#pragma warning disable 1471  // Function call that XC thinks is NULL

#include <xc.h>
#include <stdint.h>
#include <stdbool.h>
#include <string.h>
#include "hal_config.h"
#include "lf_pics.h"
#include "pic_interrupt.h"
#include "hal_time.h"
#include "hal_gpio.h"


// The simplest way to deal with devices that don't have all the ports
// pinned out, is to add 'ports' so we can use generic code throughout
#ifndef PORTB
volatile uint8_t PORTB, LATB, TRISB;
#endif

#ifndef PORTD
volatile uint8_t PORTD, LATD, TRISD;
#endif

#ifndef ODCOND
volatile uint8_t ODCOND;
#endif

#ifndef PORTE
volatile uint8_t PORTE;
#endif
volatile uint8_t LATE, TRISE;

#ifndef ODCONE
volatile uint8_t ODCONE;
#endif

#ifndef ANSELA
volatile uint8_t ANSELA;
#endif

#ifndef ANSELB
volatile uint8_t ANSELB;
#endif

#ifndef ANSELC
volatile uint8_t ANSELC;
#endif

#ifndef ANSELD
volatile uint8_t ANSELD, ANSELE;
#endif

// Other register differences between devices
#if defined(nRBPU) && !defined(_OPTION_REG_nWPUEN_POSN)
#define nWPUEN  nRBPU
#endif

// Older devices don't have individual control of pullups
#ifndef WPUA
static uint8_t  WPUA;
#endif

#ifndef WPUB
static uint8_t  WPUB;
#endif

#ifndef WPUC
static uint8_t  WPUC;
#endif

#ifndef WPUD
static uint8_t  WPUD;
#endif

#ifndef WPUE
static uint8_t  WPUE;
#endif

// Deal with ADC differences
#if !defined(ADGO) && !defined(ADGO_bit)
#define ADGO  GO
#endif

#if !defined(ADFM) && !defined(ADFM_bit)
#define ADFM  ADFM0
#endif

// Deal with DAC differences
#if defined(_18F25K83) || defined(_18F26K83) || defined(_18F26Q10)
#define DAC1MD    DACMD
#define DAC1CON   DAC1CON0
#define DAC1DATL  DAC1CON1
#endif


// We support interrupts on up to 4 pins
#define MAX_PIN_INTS      4

struct gpio_int_channel
{
    uint16_t          gpio_num;
    uint8_t           pos_edge;
    uint8_t           neg_edge;
    uint8_t           mask;
    volatile uint8_t  *flag_reg;
    volatile uint8_t  *input_reg;
    gpio_int_fn_t     gpio_isr;
};
typedef struct gpio_int_channel  gpio_int_channel_t;


static volatile uint8_t * const input_regs[]    = { &PORTA,   &PORTB,   &PORTC,   &PORTD,  &PORTE  };
static volatile uint8_t * const output_regs[]   = { &LATA,    &LATB,    &LATC,    &LATD,   &LATE   };
static volatile uint8_t * const tris_regs[]     = { &TRISA,   &TRISB,   &TRISC,   &TRISD,  &TRISE  };
static volatile uint8_t * const pullup_regs[]   = { &WPUA,    &WPUB,    &WPUC,    &WPUD,   &WPUE   };
static volatile uint8_t * const od_regs[]       = { &ODCONA,  &ODCONB,  &ODCONC,  &ODCOND, &ODCONE };
static volatile uint8_t * const ansel_regs[]    = { &ANSELA,  &ANSELB,  &ANSELC,  &ANSELD, &ANSELE };
static volatile uint8_t * const ttl_in_regs[]   = { &INLVLA,  &INLVLB,  &INLVLC,  NULL,    &INLVLE };
static volatile uint8_t * const fast_out_regs[] = { &SLRCONA, &SLRCONB, &SLRCONC, NULL,    NULL    };
static volatile uint8_t * const int_flag_regs[] = { &IOCAF,   &IOCBF,   &IOCCF,   NULL,    &IOCEF  };
static volatile uint8_t * const int_pos_edge[]  = { &IOCAP,   &IOCBP,   &IOCCP,   NULL,    &IOCEP  };
static volatile uint8_t * const int_neg_edge[]  = { &IOCAN,   &IOCBN,   &IOCCN,   NULL,    &IOCEN  };


// These chips have movable pin assignments
// These are public arrays used by other HAL modules
volatile uint8_t * const pps_outa_regs[] = { &RA0PPS, &RA1PPS, &RA2PPS, &RA3PPS, &RA4PPS, &RA5PPS, &RA6PPS, &RA7PPS };
volatile uint8_t * const pps_outb_regs[] = { &RB0PPS, &RB1PPS, &RB2PPS, &RB3PPS, &RB4PPS, &RB5PPS, &RB6PPS, &RB7PPS };
volatile uint8_t * const pps_outc_regs[] = { &RC0PPS, &RC1PPS, &RC2PPS, &RC3PPS, &RC4PPS, &RC5PPS, &RC6PPS, &RC7PPS };


static int  pin_count = 0;

// Lookup table to optimise variable bit shifts
static const uint8_t bitmask[] = { 1, 2, 4, 8, 0x10, 0x20, 0x40, 0x80 };

// List of registered interrupts
static gpio_int_channel_t  pin_ints[MAX_PIN_INTS];

// Number of registered interrupts
static uint8_t  num_pin_ints;
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

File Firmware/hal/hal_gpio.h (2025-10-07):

/*
 * Embedded code hardware abstraction layer API
 *    - GPIO and ADC/DAC access functions
 *
 * To maintain compatibility across all MCU types, a standard numbering scheme
 * is used to describe GPIO pins.  On chips with numbered ports/pins we use a
 * 16-bit value with the top byte being the port and the bottom byte is the pin
 * e.g. 0x0102 is port 1, pin 2.  On chips with lettered ports, A is port 0
 * e.g. 0x0102 is port B, pin 2.  The same scheme is used for analog pins so
 * there is no need to know how the ADC channels map to GPIO pins, it is the
 * responsibility of the HAL code to deal with it.
 *
 * Functions are also provided to set/get/configure whole (digital) ports.
 * These are designed to be used for parallel interfaces and should not be used
 * to mop up multiple GPIO pin assignments as that defeats portability between
 * CPUs with different sized ports.  More complex functions such as interrupts
 * are only available for individual pins.
 *
 * A project should have a hal_config.h file that defines the pins used for
 * each purpose and an emul_config.h that defines what range of ports/pins
 * the target MCU has.  These 2 files should be contained within the project
 * folder and included in the project path so that the generic HAL code picks
 * up the correct file for each different project.  For example if you write
 * #define LED  0x0102  in hal_config.h, then when you want the LED pin to
 * go high, you can say gpio_set(LED, HIGH); and if you change the pin or
 * have two boards with different pins, the only definintion of the GPIO
 * pins are contained within hal_config.h.  Porting to a different MCU just
 * requires a new hal_config.h and building the code with the HAL files for
 * the new MCU.
 *
 * Copyright Debug Innovations Ltd. 2016-2022
 */

#ifndef HAL_GPIO_H
#define HAL_GPIO_H

#include <stdint.h>

// Make it usable with C and C++
#ifdef __cplusplus
extern "C" {
#endif


/* This value is used to indicate to the gpio functions that a pin
 * isn't to be used.  In other words, if you pass this value to
 * a gpio function, it will do nothing.  In hal_config.h we can use
 * this value to indicate that, for a particular PCB, a certain
 * function is not available and this means we don't need #ifdef's
 * for each board type scattered throughout the code.
 */
#define GPIO_NOT_CONNECTED   (0xFFFF)

/* HIGH/LOW definition for use with GPIO set/get */
#define LOW                  (0)
#define HIGH                 (1)

/* GPIO pin modes for gpio_configure_pin()
 * OR these together to describe the required pin properties
 */
/* Pin direction */
#define PIN_DIR_IN           (0x00)
#define PIN_DIR_OUT          (0x01)
#define PIN_OPEN_DRAIN       (0x02)
#define PIN_DIR_MASK         (0x01)

/* Analog or digital mode */
#define PIN_MODE_DIGITAL     (0x00)
#define PIN_MODE_ANALOG      (0x10)

/* Initial value for a digital output pin, ignored for inputs and analog pins
 * This will be applied before the pin becomes an output to avoid glitches
 */
#define PIN_SET_LOW          (0x00)
#define PIN_SET_HIGH         (0x08)

/* Pullup/downs */
#define PIN_FLOATING         (0x00)
#define PIN_PULL_UP          (0x40)
#define PIN_PULL_DOWN        (0x80)

/* Output drive strength/speed (only applies to digital outputs).
 * Not all MCUs will support this and different drivers will interpret
 * this request differently.  For default output drive, omit this bit.
 */
#define PIN_HIGH_CURRENT     (0x04)
#define PIN_HIGH_SPEED       (0x04)

/* Input threshold or hysteresis (only applies to digital inputs).
 * Not all MCUs will support this and different drivers will interpret
 * this request differently.  For default input levels, omit this bit.
 */
#define PIN_TTL_INPUT_LEVEL  (0x04)
#define PIN_SCHMITT_INPUT    (0x04)

/* Hybrid definitions for common use cases */
#define PIN_DIGITAL_IN       (PIN_MODE_DIGITAL | PIN_DIR_IN)
#define PIN_DIGITAL_OUT      (PIN_MODE_DIGITAL | PIN_DIR_OUT)
#define PIN_ANALOG_IN        (PIN_MODE_ANALOG | PIN_DIR_IN)
#define PIN_ANALOG_OUT       (PIN_MODE_ANALOG | PIN_DIR_OUT)

/* Analog channel specifier flag - see analog_input_get() */
#define ADC_CHANNEL_NUM      (0x8000)

/* This value is OR'ed with 1/0 for the pin_level parameter when
 * software calls a GPIO interrupt handler.  Normal hardware
 * interrupts simply use 1 and 0.
 */
#define GPIO_SW_INT          (0x80)


/* GPIO interrupt setup settings */
enum gpio_int_setting_type
{
    // All possible interrupt conditions.
    // Chips that don't support a specific condition
    // will use the closest substitute setting.
    INT_NEVER = 0,
    INT_WHEN_HIGH,
    INT_WHEN_LOW,
    INT_ON_RISING_EDGE,
    INT_ON_FALLING_EDGE,
    INT_ON_BOTH_EDGES,

    // Number of conditions above -
    // this should always be last in the list
    INT_NUM_SETTINGS,

    // Special qualifier to be OR'ed with the above
    WAKE_ON_INT = 0x80
};
typedef enum gpio_int_setting_type  gpio_int_setting_t;
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
